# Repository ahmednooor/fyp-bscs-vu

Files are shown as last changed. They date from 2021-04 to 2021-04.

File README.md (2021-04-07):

# IoT based Smart Weather Reporting System

Final year project (CS619 Spring & Fall 2020) for BSCS at Virtual University of Pakistan.

Student Name: Ahmed Noor E Alam

Supervisor: Kalim Ullah

## Introduction

An IoT based system that helps you to monitor live weather data (temperature, humidity and rain) at a location of your choice and set critical limits to get notified when they are crossed.

## Technologies Used

### Hardware Components
1. NodeMCU ESP8266 (Wi-Fi Enabled & Arduino SDK Compatible Microcontroller)
2. DHT22 Temperature + Humidity Sensor
3. YL-83 / MH-RD Rain Drop Sensor
4. U-Blox Neo 6m GPS Module
5. 16x2 I2C LCD Module

### Software Components
1. IoT Device: C/C++ Arduino SDK
2. Web Server: Python Flask
3. Admin Panel: ReactJS
4. Android App: Java Android SDK

## Architectural Overview

<kbd>
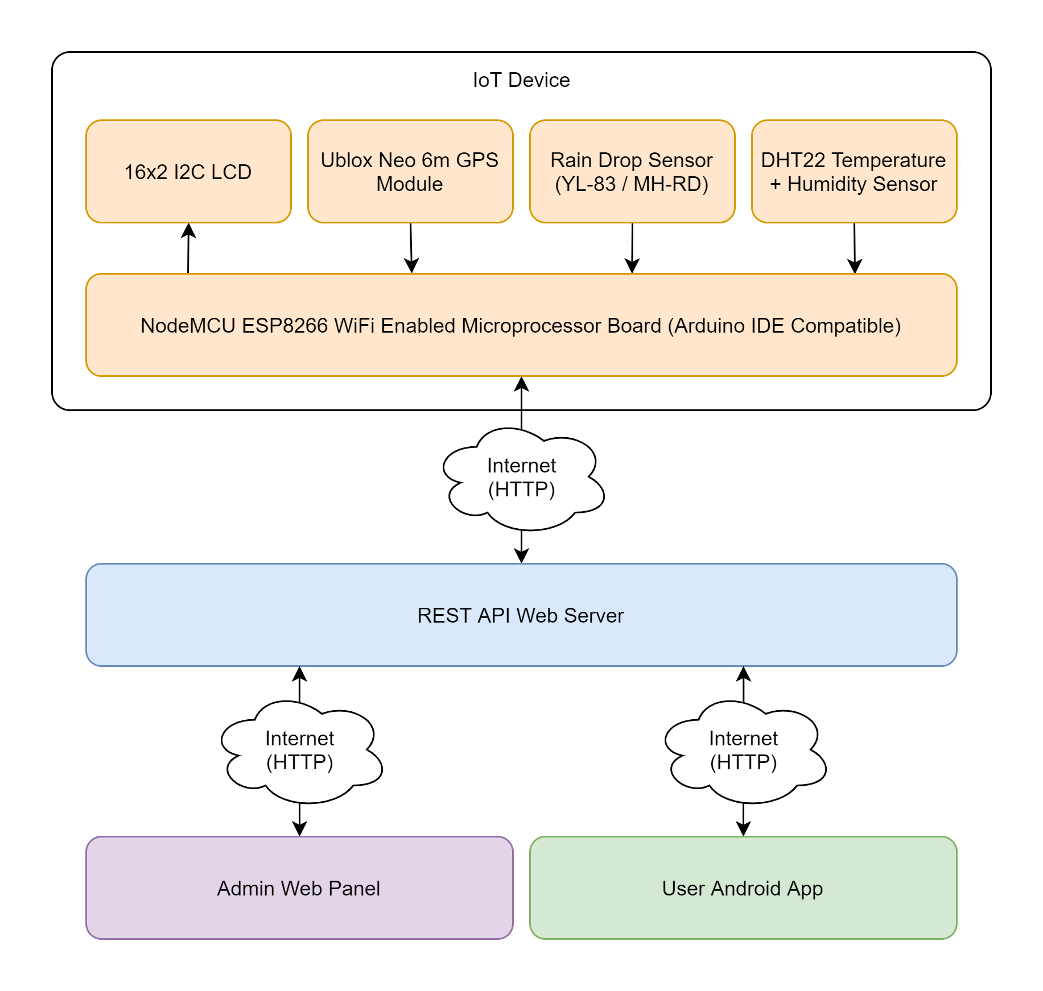
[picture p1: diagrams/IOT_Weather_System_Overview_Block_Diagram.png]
Overview block diagram
    
</kbd>
<br />

## IoT Device Schematic
<kbd>
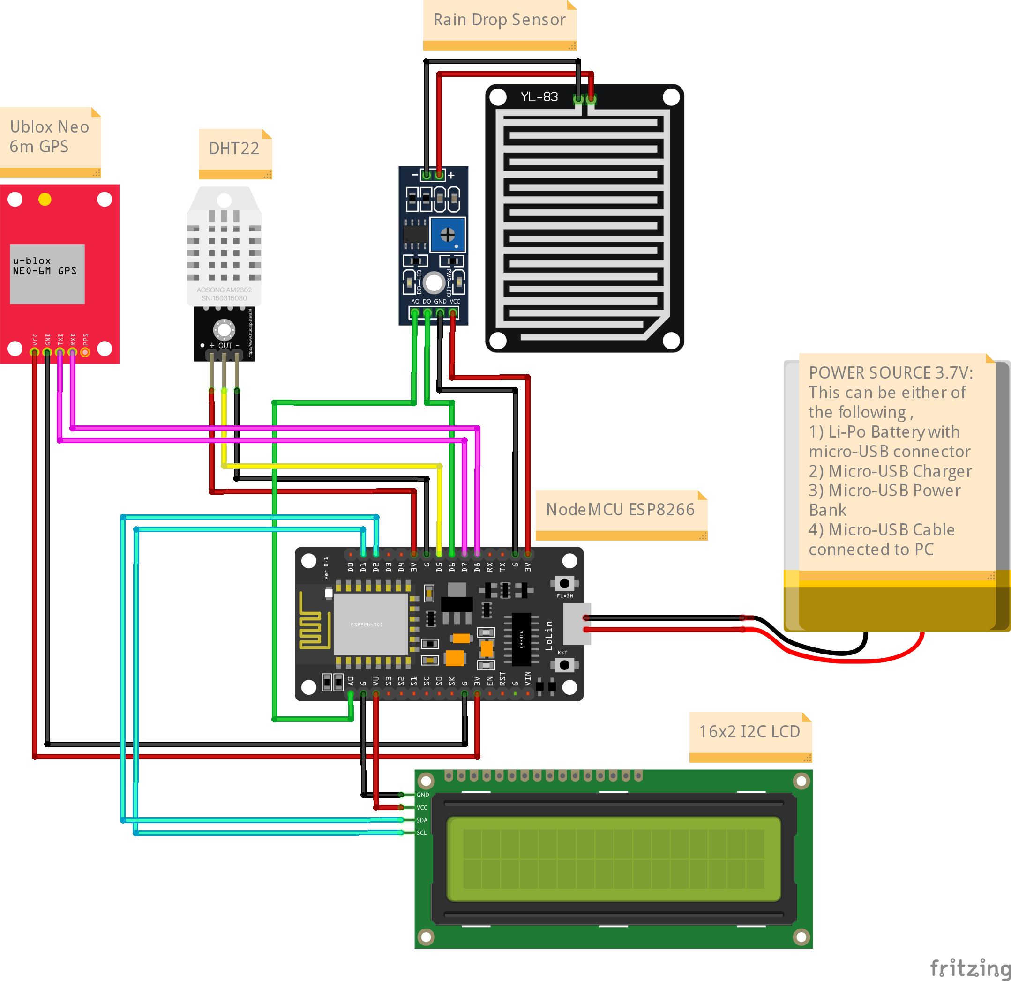
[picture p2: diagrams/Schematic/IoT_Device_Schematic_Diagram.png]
IoT device schematic diagram
    
</kbd>
<br />

### Pin Mappings

| Ublox Neo 6m GPS | NodeMCU ESP8266 |
| --- | --- |
| VCC | 3V3 |
| GND | GND |
| TXD | D7 |
| RXD | D8 |

| DHT 22 | NodeMCU ESP8266 |
| --- | --- |
| + | 3V3 |
| OUT | D5 |
| - | GND |

| Rain Drop Sensor | NodeMCU ESP8266 |
| --- | --- |
| VCC | 3V3 |
| GND | GND |
| DO | D6 |
| AO | A0 |

| 16x2 I2C LCD | NodeMCU ESP8266 |
| --- | --- |
| VCC | VV |
| GND | GND |
| SCL | D1 |
| SDA | D2 |

## PCB Design
<kbd>
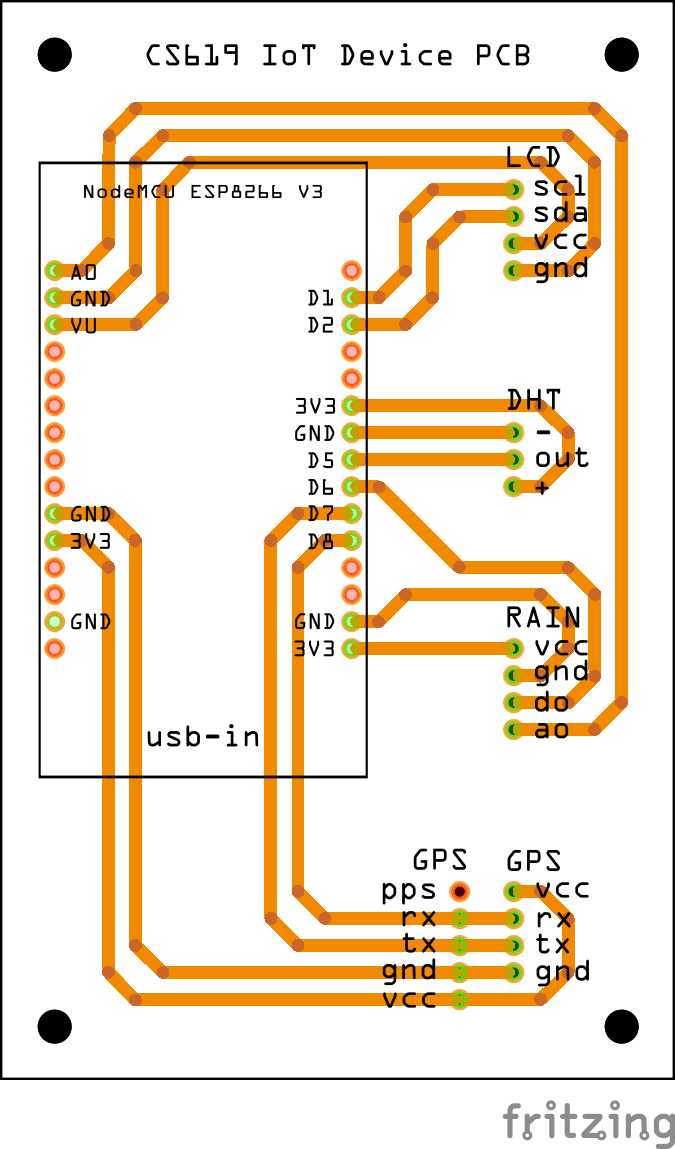
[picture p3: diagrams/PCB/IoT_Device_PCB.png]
PCB design
    
</kbd>
<br />

## Final Deliverable Screenshots and Images

### User Android App
<kbd>
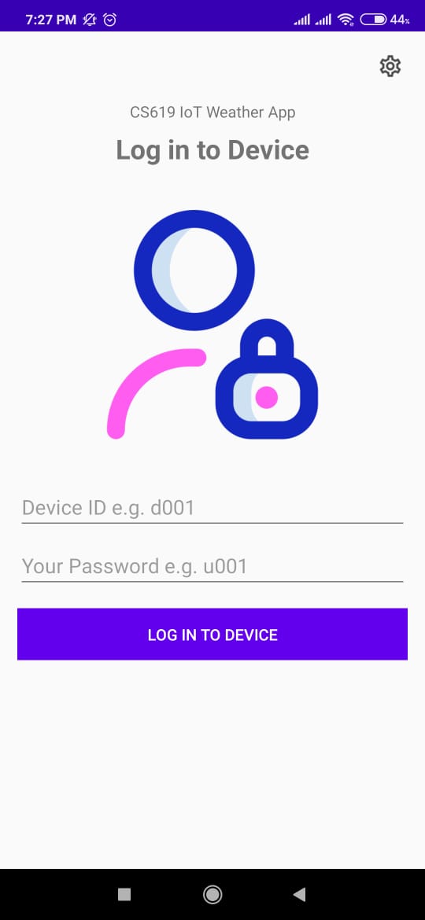
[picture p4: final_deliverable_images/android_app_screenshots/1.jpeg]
User Android app login screenshot
    
</kbd>
<kbd>
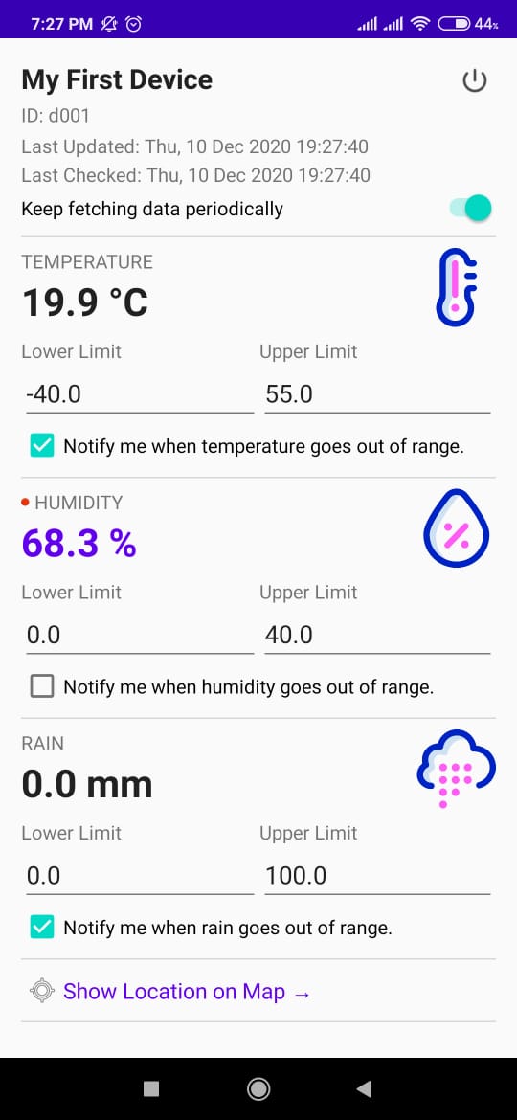
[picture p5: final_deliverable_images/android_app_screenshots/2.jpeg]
User Android app dashboard screenshot
    
</kbd>
<kbd>
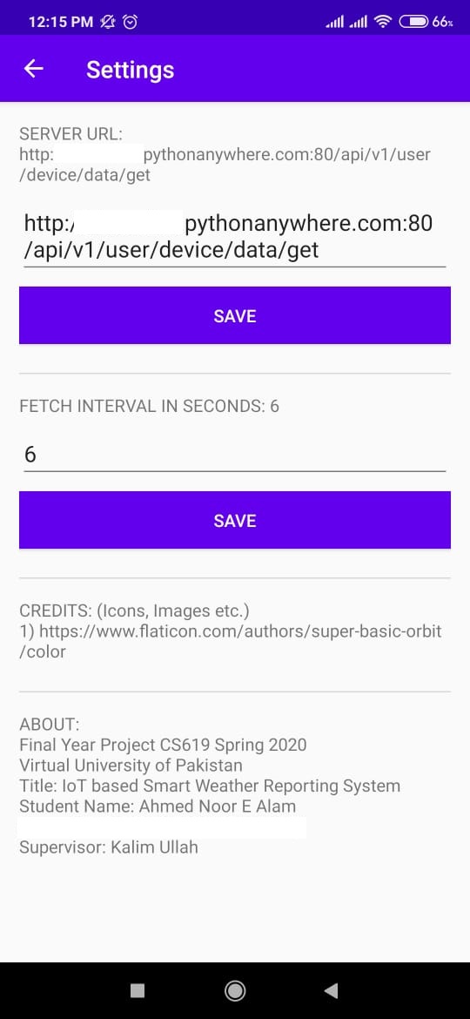
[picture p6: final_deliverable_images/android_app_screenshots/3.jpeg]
User Android app settings screenshot
    
</kbd>
<br />

### IoT Device
<kbd>
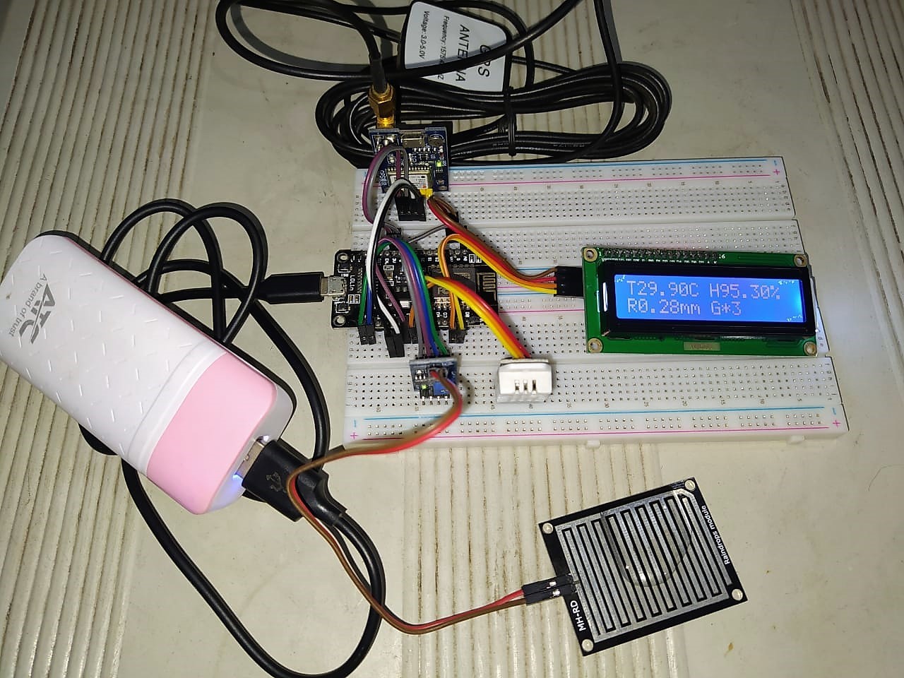
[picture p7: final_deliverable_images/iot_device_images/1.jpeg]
IoT device image
    
</kbd>
<kbd>
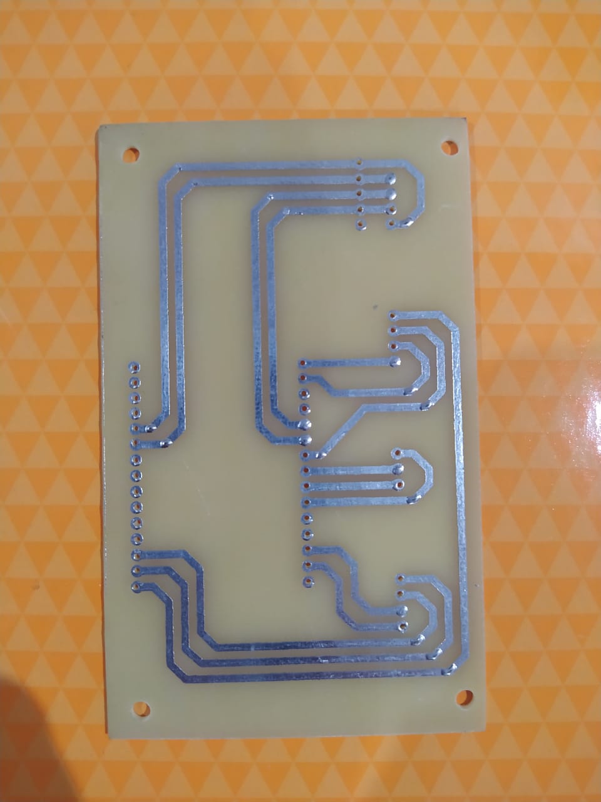
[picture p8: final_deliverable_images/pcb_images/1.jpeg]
PCB image
    
</kbd>
<br />
<kbd>
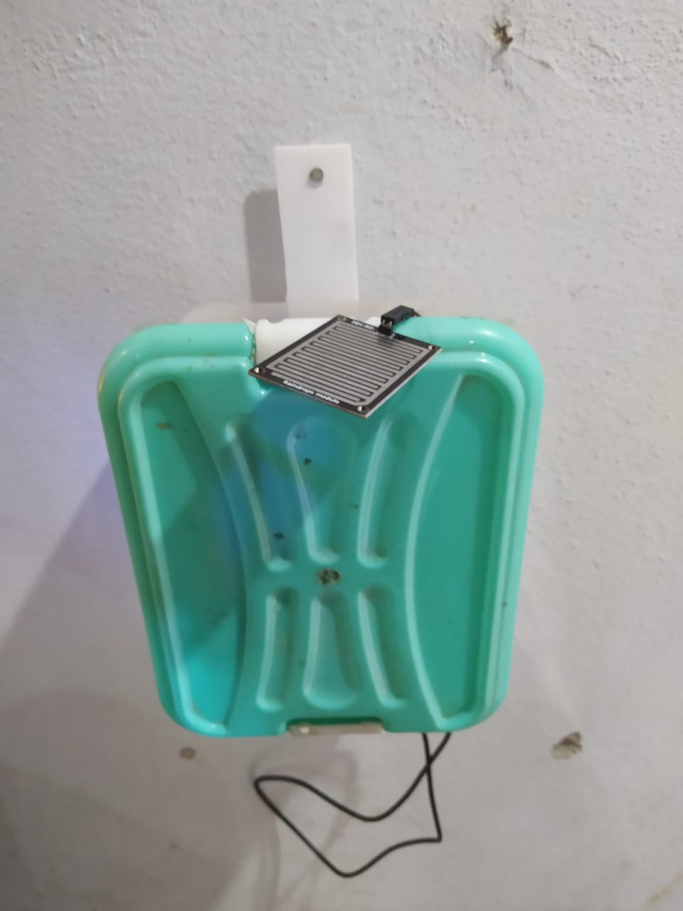
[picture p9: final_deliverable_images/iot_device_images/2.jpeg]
IoT device image
    
</kbd>
<kbd>
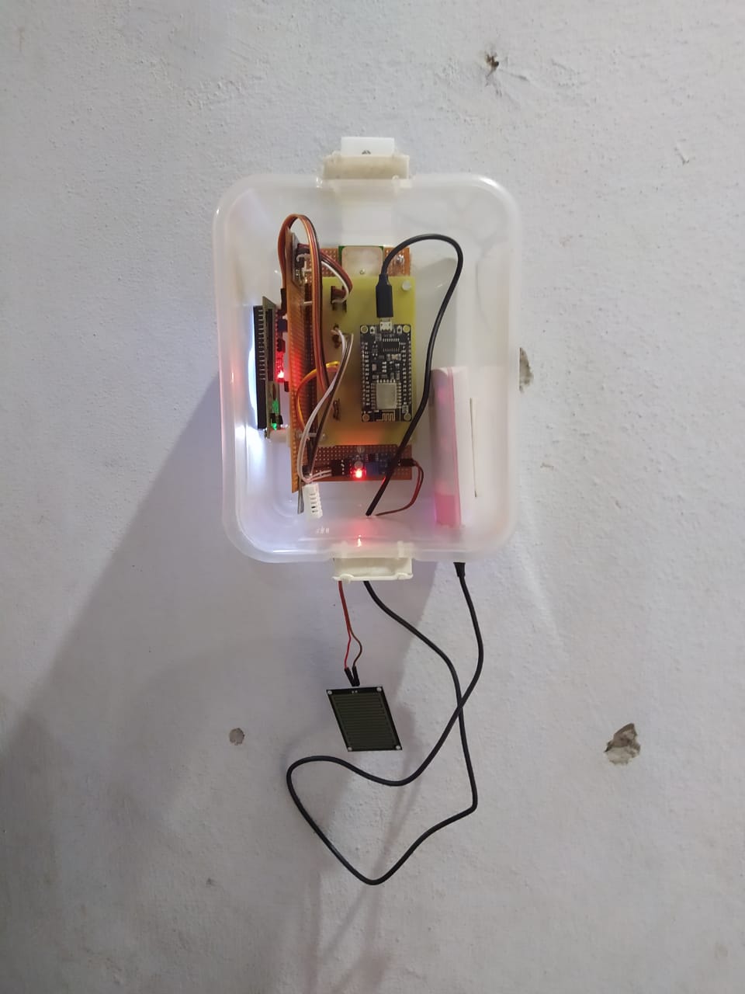
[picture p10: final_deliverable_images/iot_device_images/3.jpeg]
IoT device image
    
</kbd>
<br />
<kbd>
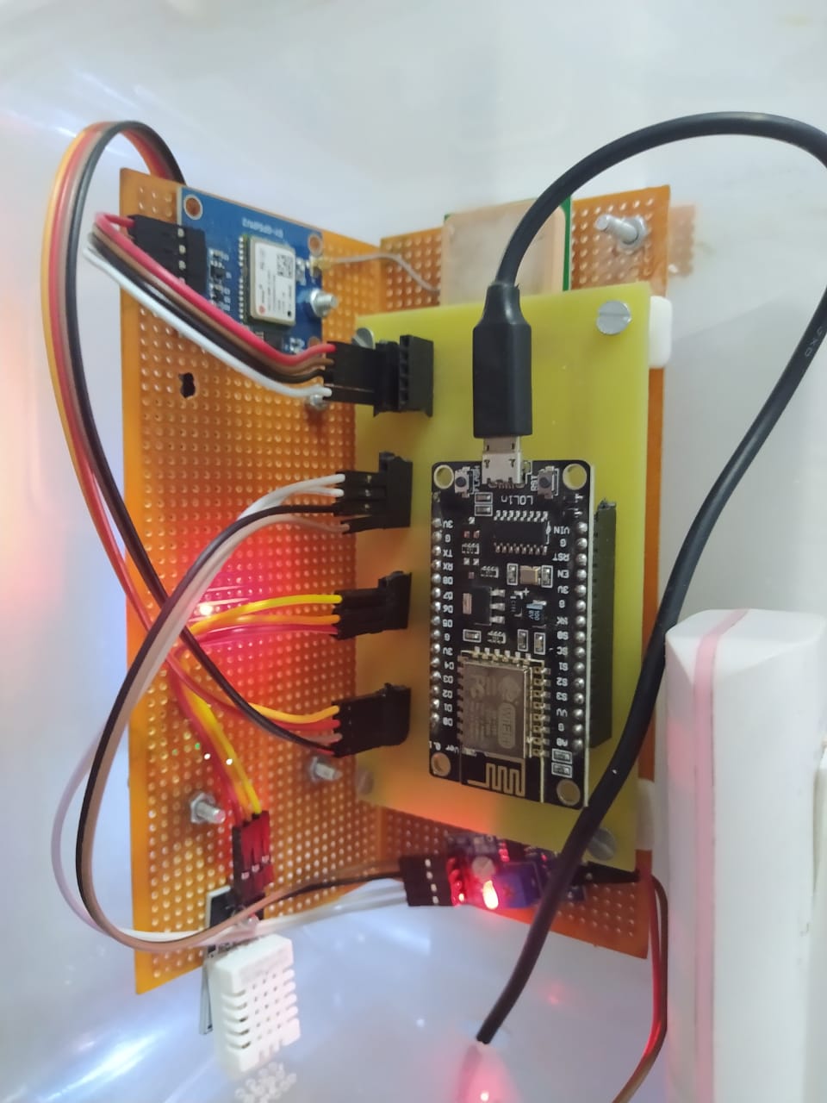
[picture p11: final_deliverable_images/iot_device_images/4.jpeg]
IoT device image
    
</kbd>
<kbd>
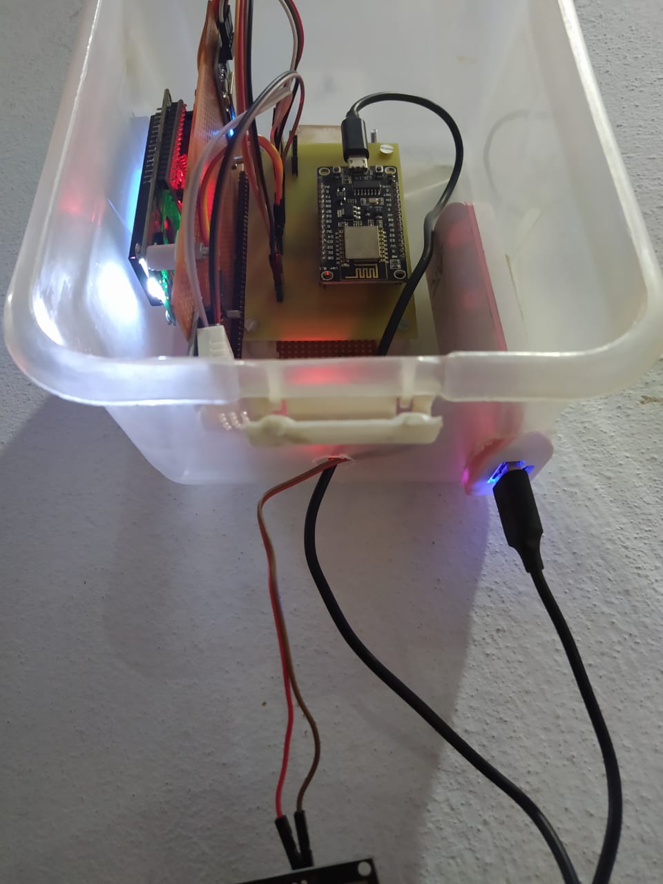
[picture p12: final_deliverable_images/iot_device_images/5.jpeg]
IoT device image
    
</kbd>
<br />
<kbd>
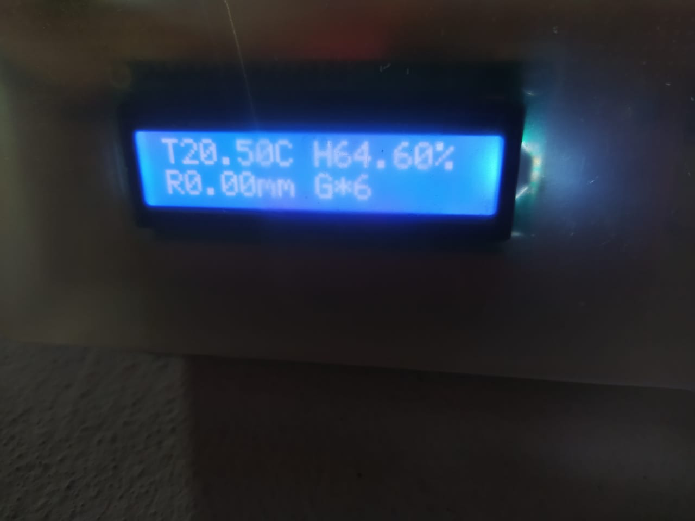
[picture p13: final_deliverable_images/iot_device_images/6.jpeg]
IoT device image
    
</kbd>
<br />

### Admin Web Panel
<kbd>
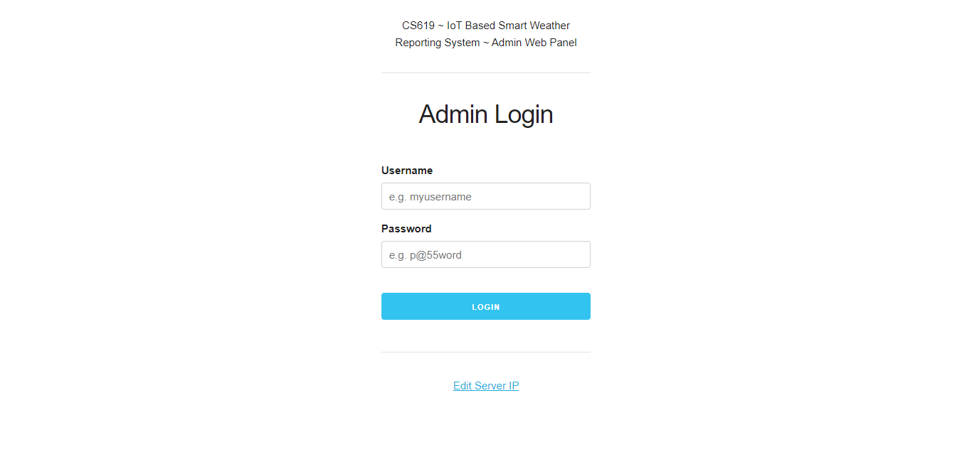
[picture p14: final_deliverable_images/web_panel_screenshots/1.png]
Admin web panel login screenshot
    
</kbd>
<br>
<kbd>
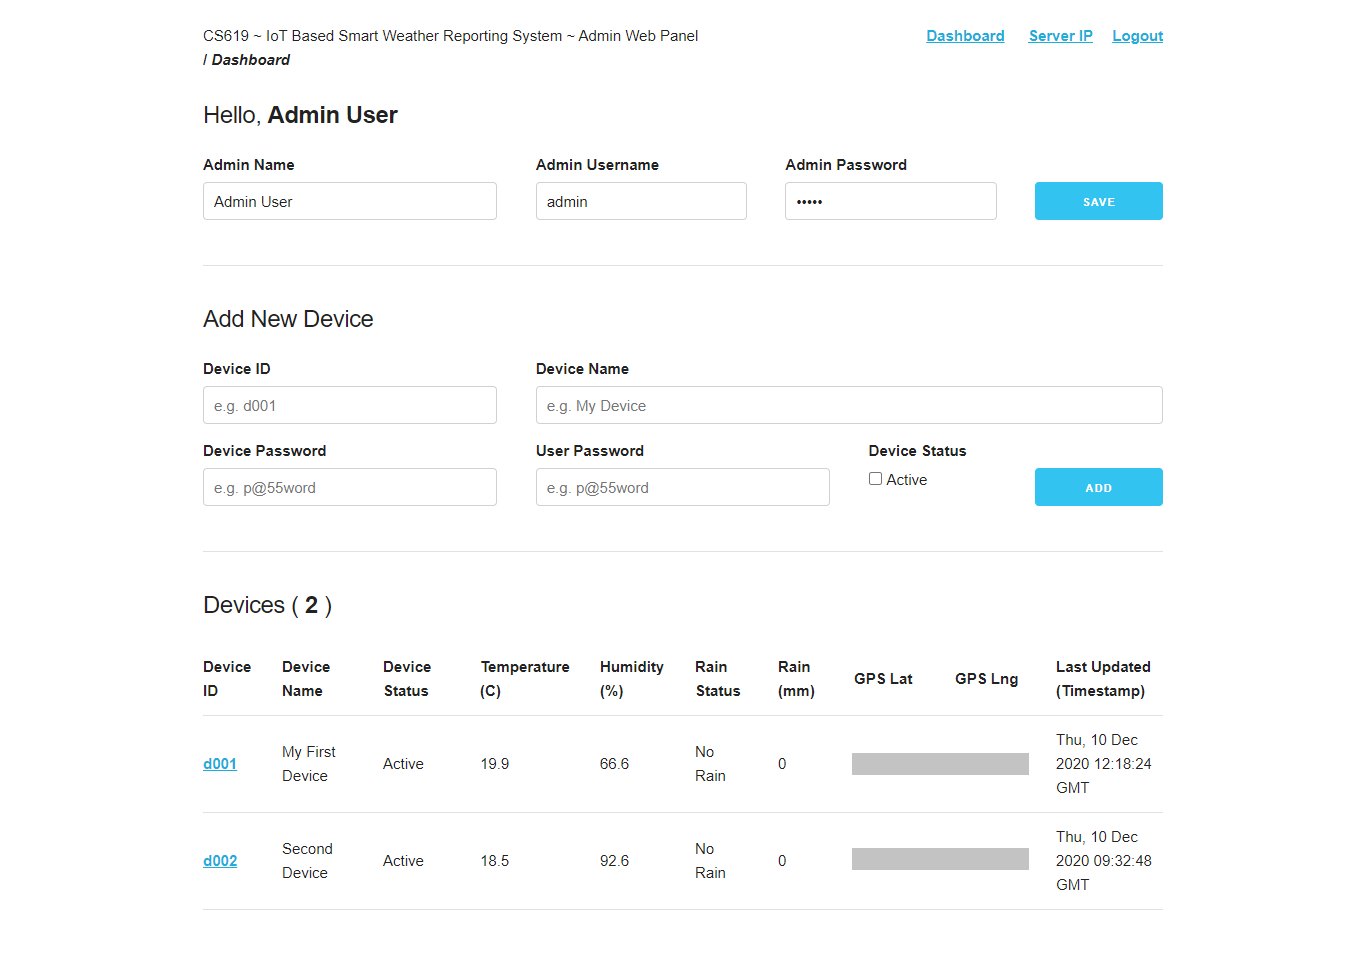
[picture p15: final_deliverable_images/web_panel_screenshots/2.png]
Admin web panel dashboard screenshot
    
</kbd>
<br>
<kbd>
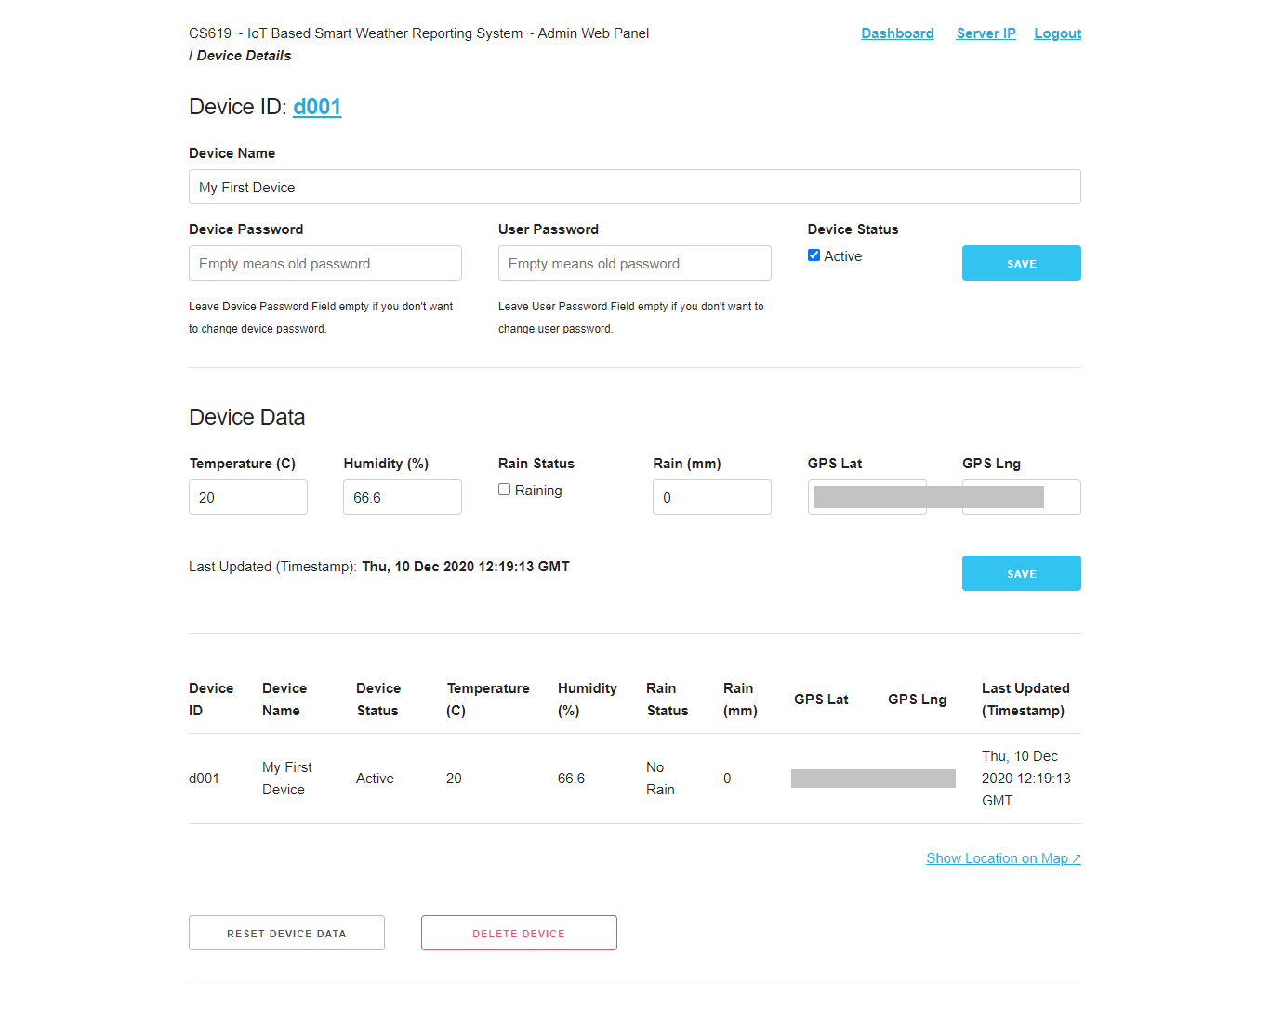
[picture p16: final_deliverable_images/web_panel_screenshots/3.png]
Admin web panel device page screenshot
    
</kbd>
<br>
<kbd>
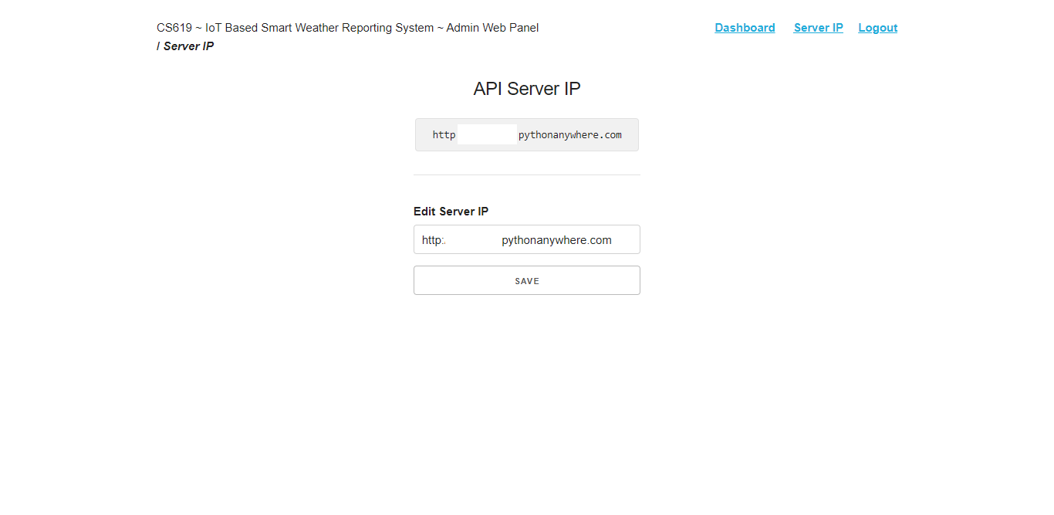
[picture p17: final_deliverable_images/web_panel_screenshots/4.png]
Admin web panel server ip page screenshot
    
</kbd>
<br>

## Setup and Usage Instructions

The system has four components.

1. Python Web Server
2. Admin Web Panel
3. IoT Device
4. User Android App

### 1. Python Server (Deploy on pythonanywhere.com):

1. Copy contents of `rest_api_web_server` in to a directory with the same name on pythonanywhere via either uploading a zip and then unzipping via opening a terminal or via cloning the git repo.
2. Creat new flask web app in root of the same directory. Just make sure the new file name should not override any pre-existing ones. By default the new file is named `flask_app.py`.
3. Clear the contents of the newly created `flask_app.py` file and add `from run import app` then save and reload the web app.

**The following details will be used for setting up the remaining components.**
- **Server IP:** &lt;your_username&gt;.pythonanywhere.com
  > Or if you deployed on a VPS, then your vps host name or ip.
- **Port:** 80 
  > Or if you deployed your app on other port, use that.
- **DEFAULT_SERVER_URL** i.e. ip+port+api_endpoint for android app: http://&lt;your_username&gt;.pythonanywhere.com:80/api/v1/user/device/data/get

### 2. Admin Web Panel:

1. Open terminal in `admin_web_panel` directory.
2. Type `npm install`.
3. Type `npm run build`. You will get the build of your web app in `build` directory.
4. Open `index.html` in browser and go to `Server IP` link and edit the server ip with yours. You don't need to add api_endpoint in the field. Just server ip + port e.g. `http://<your_username>.pythonanywhere.com:80`
5. Login with admin credentials. Default username is `admin` and password is `12345`.
6. Add a new device with new `Device ID`, `Device Password` and `User Password`.
   > Make sure that you check the `active` box while creating a new device, otherwise the server will not store new data from that device.

### 3. IoT Device:

1. Install ESP8266 Core Library for Arduino IDE by following the tutorial from the link below.
   > Link: https://randomnerdtutorials.com/how-to-install-esp8266-board-arduino-ide/
2. Unzip and copy the contents of `iot_device/libraries.zip` in to the libraries folder of your Arduino user directory i.e. `"This PC/Documents/Arduino/libraries/"`.
3. Check the `Schematic Diagram` from `diagrams` directory for wiring details and attach all the components to the board according to the wiring shown in the diagram.
4. Open `iot_device/ESP8266_Sketch/ESP8266_Sketch.ino` in your Arduino IDE and update your WiFi Name `#define SSID "..."` and WiFi Password `#define PASS "..."`.
5. Update `#define REST_SERVER_IP "..."` with your Server IP e.g. `http://<your_username>.pythonanywhere.com` and `#define REST_SERVER_PORT "..."` with the port where you deployed the python server  e.g. `:80`.
6. Copy the same `Device ID` and `Device Password` that you entered in the `Admin Web Panel`, and paste them in your IoT Sketch for `#define DEVICE_ID "..."` and `#define DEVICE_PASSWORD "..."`.
5. Connect your board to computer with Micro USB cable, and then select `NodeMCU v1.0 (ESP-12E Module)` from `Tools > Board: > ...` just like in installation instruction, then select `com port` and upload the sketch. Open Serial Monitor in your Arduino IDE to see output.
   > Note: The GPS module takes some time to connect to satellites.

### 4. User Android App:

1. Open in android studio.
2. Open `DatabaseActivity` and edit `DEFAULT_SERVER_URL` with your server url i.e. host + port + api_endpoint.
   e.g. `DEFAULT_SERVER_URL = "http://<your_username>.pythonanywhere.com:80/api/v1/user/device/data/get"`
3. Add `google_maps_key` in `.../src/debug/res/values/google_maps_api.xml` and `.../src/release/res/values/google_maps_api.xml` with your api key.
4. Run the app or build apk and install.
5. Use the same `Device ID` and `User Password` that you entered in the `Admin Web Panel`, and enter it in the login screen of mobile app to login and access device data.

~ *End of file.* ~

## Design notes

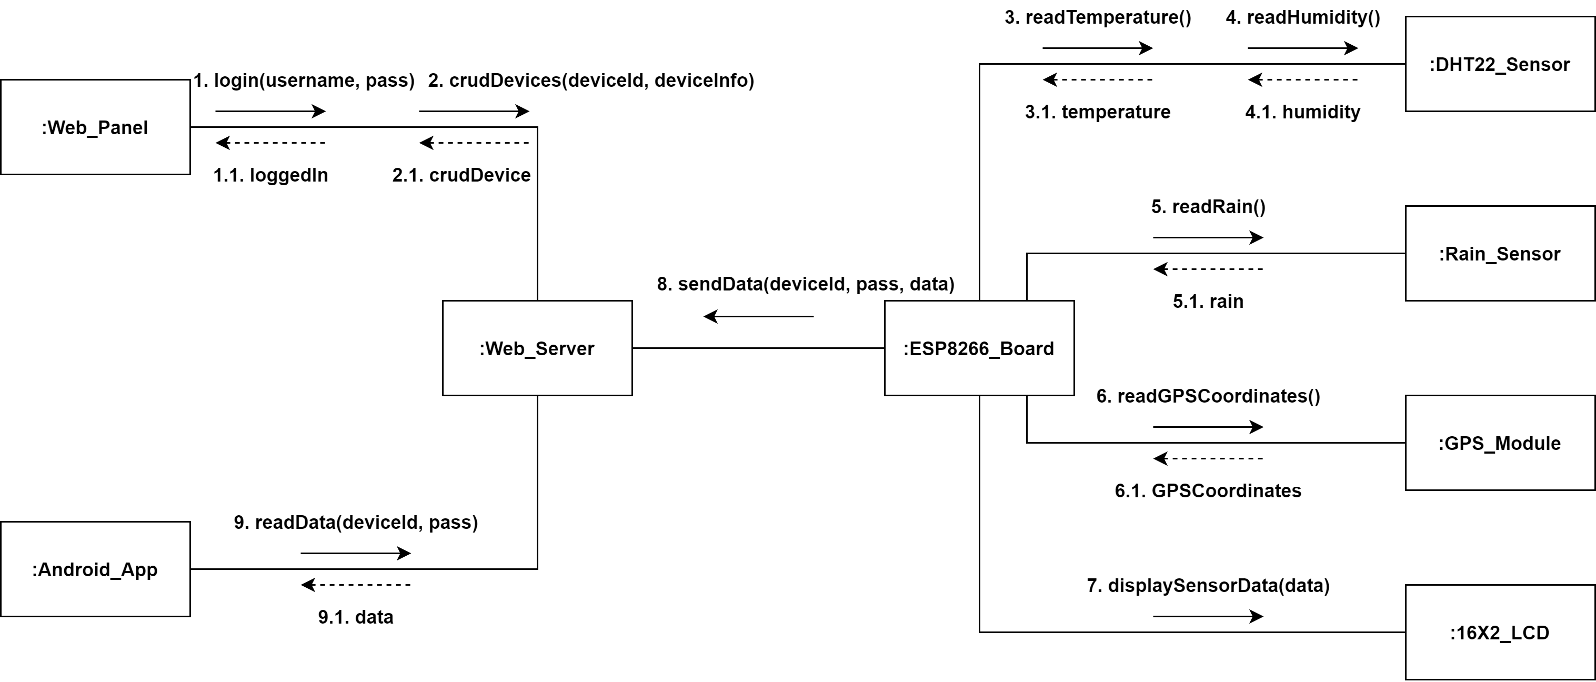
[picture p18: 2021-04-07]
diagrams/Communication_Diagram.png

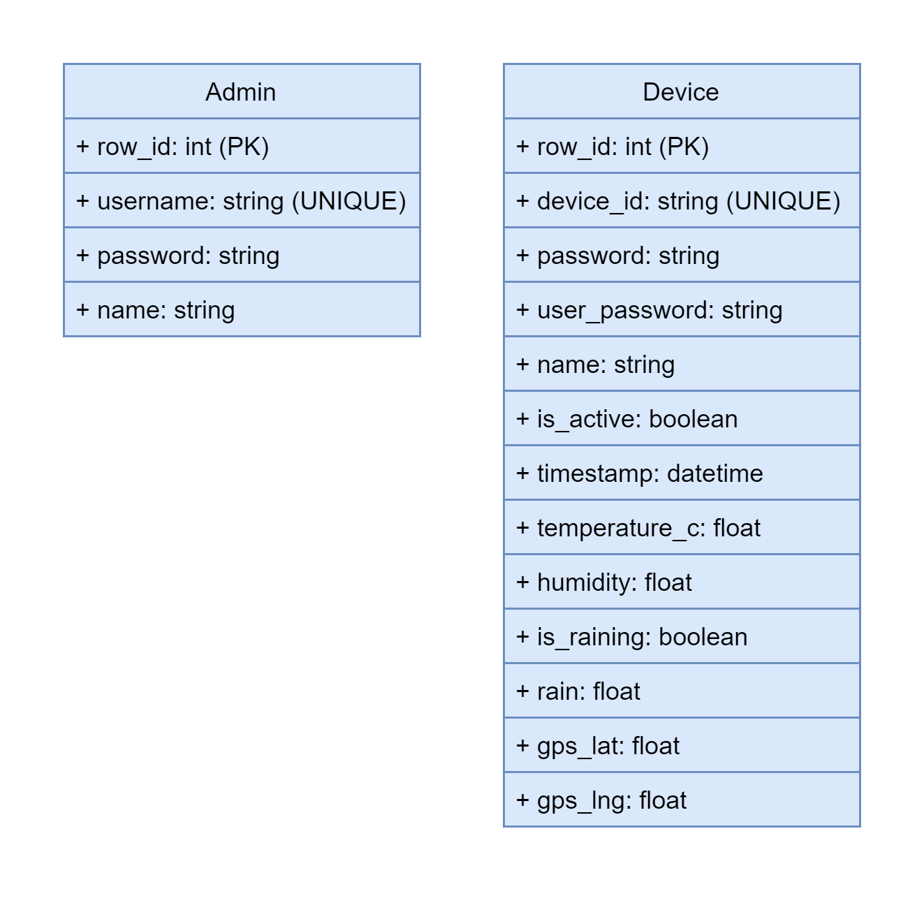
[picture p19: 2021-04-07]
diagrams/Database_Tables.png

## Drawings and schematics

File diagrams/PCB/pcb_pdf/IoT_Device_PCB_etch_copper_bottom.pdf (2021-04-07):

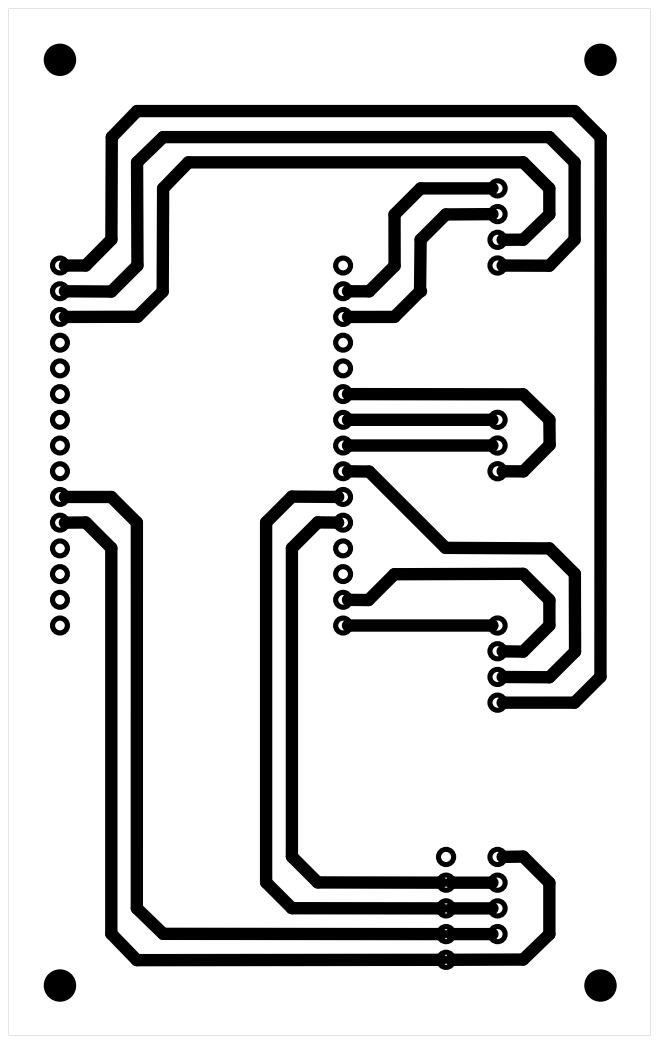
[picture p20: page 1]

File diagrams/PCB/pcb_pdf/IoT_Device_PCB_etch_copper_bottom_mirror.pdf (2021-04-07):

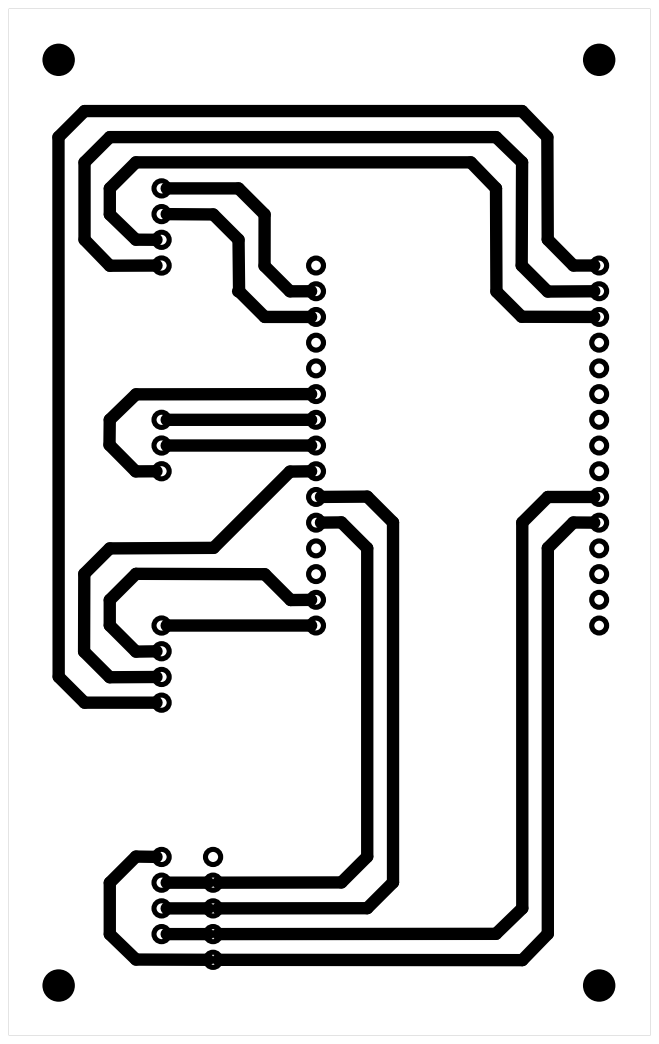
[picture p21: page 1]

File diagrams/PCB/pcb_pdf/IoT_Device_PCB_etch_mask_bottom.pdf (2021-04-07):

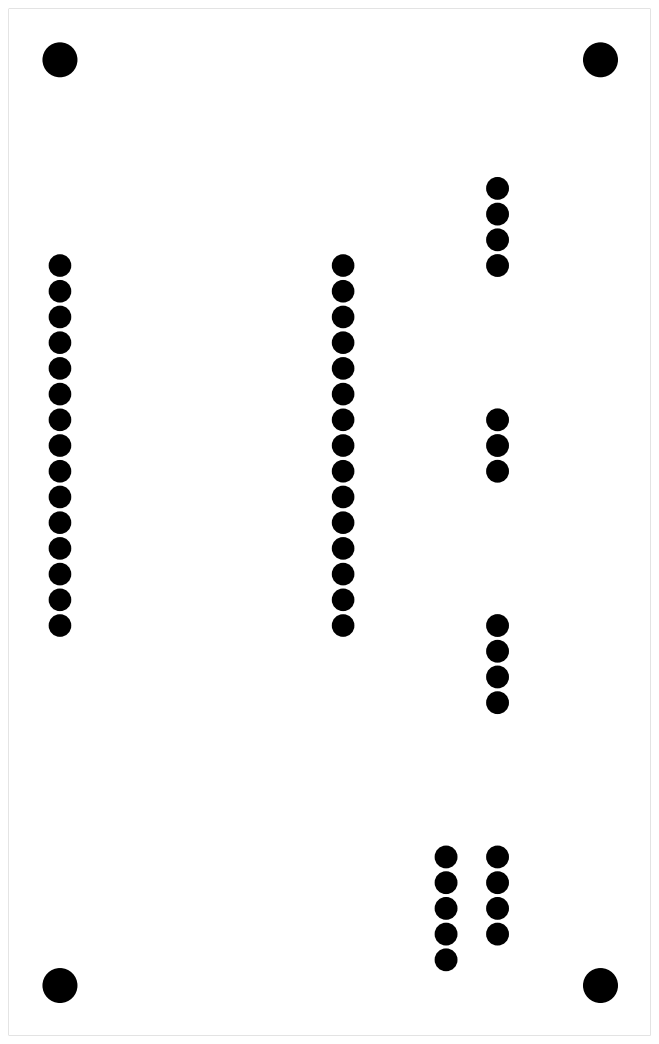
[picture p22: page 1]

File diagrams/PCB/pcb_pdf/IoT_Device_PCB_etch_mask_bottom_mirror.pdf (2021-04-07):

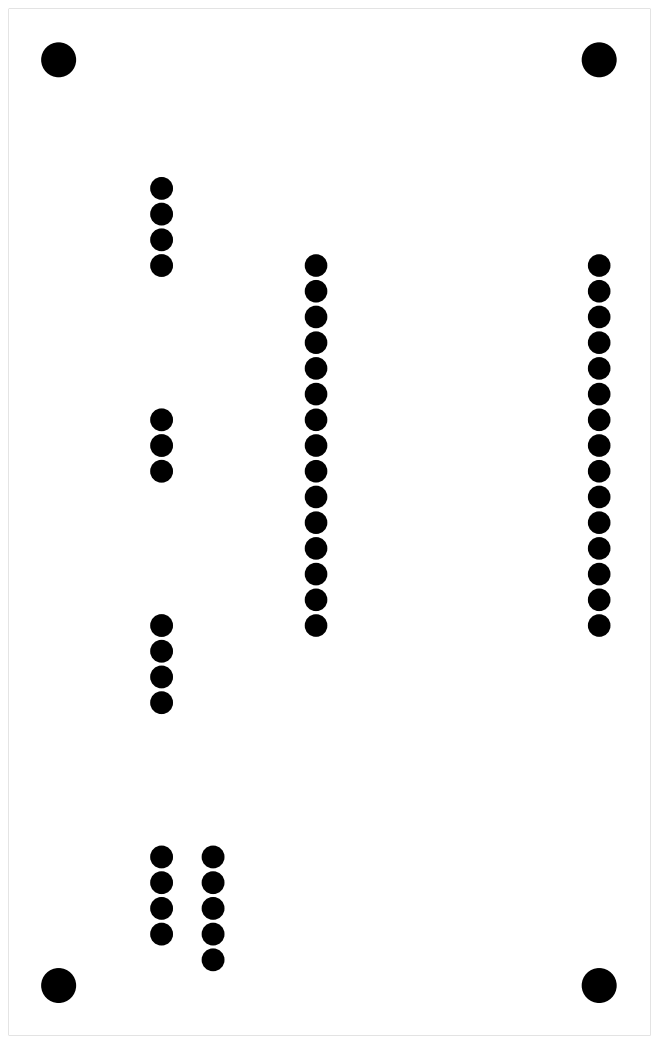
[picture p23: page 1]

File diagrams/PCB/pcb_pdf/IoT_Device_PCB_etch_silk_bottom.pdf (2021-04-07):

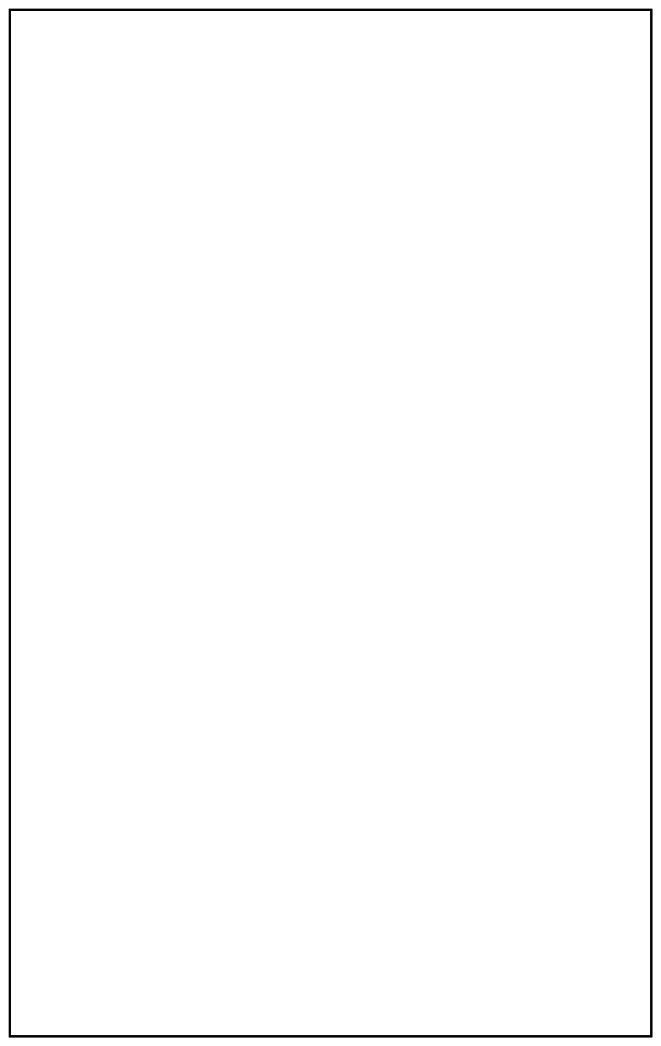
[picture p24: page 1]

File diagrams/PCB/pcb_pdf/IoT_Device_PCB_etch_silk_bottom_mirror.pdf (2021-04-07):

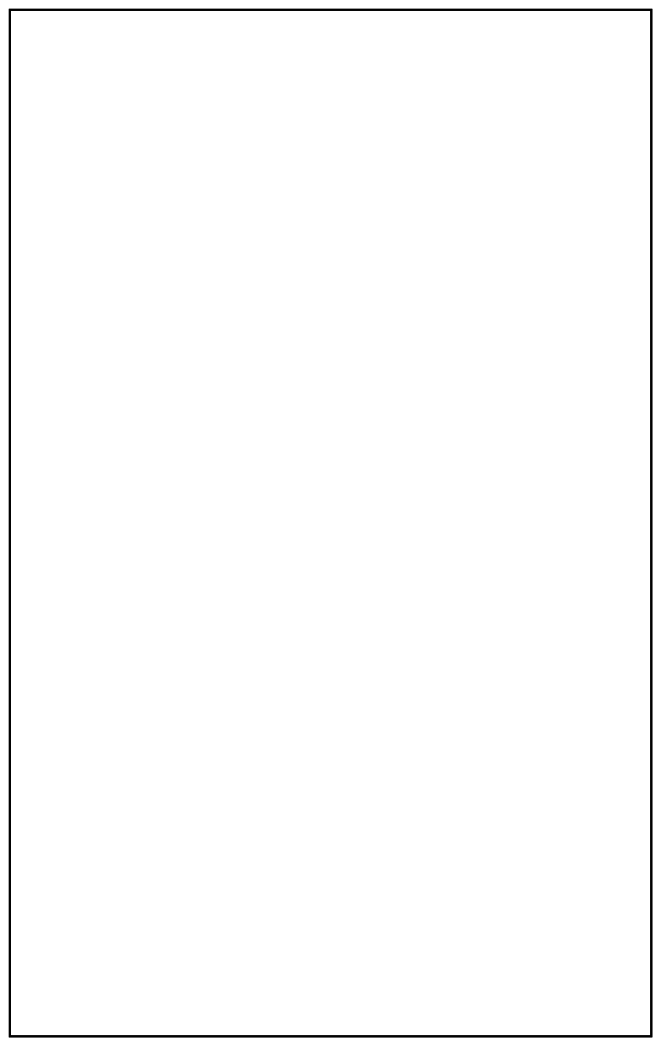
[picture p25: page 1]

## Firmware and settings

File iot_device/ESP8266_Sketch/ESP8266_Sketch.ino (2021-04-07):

// CS619 VU FYP Spring 2020
// Useful links and credits:
// https://robojax.com/learn/arduino/?vid=robojax_ESP8266_NodeMCU_DHT
// https://github.com/sarful/Interface-raindrop-sensor-to-NodeMcu-For-Beginner/blob/master/rain_sensor.ino.ino
// https://cdn.instructables.com/FJC/J4AP/JH8JBTHA/FJCJ4APJH8JBTHA.LARGE.jpg
// https://lastminuteengineers.com/wp-content/uploads/arduino/ESP-12E-Development-Board-ESP8266-NodeMCU-Pinout.png

#include <math.h>
#include <DHT.h>
#include <Adafruit_Sensor.h>

#include <ESP8266WiFi.h>
#include <WiFiClient.h>
#include <ESP8266WebServer.h>
#include <ESP8266mDNS.h>
#include <ESP8266HTTPClient.h>

#include <TinyGPS++.h>
#include <SoftwareSerial.h>

#include <Wire.h>
#include <LiquidCrystal_I2C.h>

// --- Digital (Dx) GPIO Pin Mappings ---
#define PIN_D0 16
#define PIN_D1 5
#define PIN_D2 4
#define PIN_D3 0
#define PIN_D4 2
#define PIN_D5 14
#define PIN_D6 12
#define PIN_D7 13
#define PIN_D8 15

// --- DHT settings ---
#define DHTPIN PIN_D5 // what digital pin we're connected to
// Uncomment "DHTTYPE" the one you're using!
// #define DHTTYPE DHT11   // DHT 11
#define DHTTYPE DHT22 // DHT 22  (AM2302), AM2321
// #define DHTTYPE DHT21   // DHT 21 (AM2301)
DHT dht(DHTPIN, DHTTYPE);
float temperatureC = 0.0; // temperature in Celsius
float humidity = 0.0;     // humidity in %

// --- Rain Drop Sensor Settings ---
#define RAIN_ANALOGUE_PIN A0    // input for LDR and rain sensor
#define RAIN_DIGITAL_PIN PIN_D6 // enable reading Rain sensor
int rainAnalogueValue = 0;      // variable to store the value coming from Rain sensor
int rainDigitalValue = 0;       // variable to store the value coming from Rain sensor
double rainMeasure = 0.0;       // variable to store rain measurement in mm

// --- gps settings ---
TinyGPSPlus gps;
#define RXPin PIN_D7             // TX from gps goes into RX of board
#define TXPin PIN_D8             // RX from gps goes into TX of board
SoftwareSerial gpsSerial(RXPin, TXPin); // (RX, TX) The serial connection to the GPS device
float latitude, longitude;
int year, month, date, hour, minute, second;
String date_str, time_str, lat_str, lng_str;
int pm;
uint32_t sats = 0;
// NOTE: also see https://www.esp8266.com/viewtopic.php?f=32&t=3829

// --- lcd settings ---
// set LCD address, number of columns and rows
// if you don't know your display address, run an I2C scanner sketch
#define LCD_ADDR 0x27 // I2C LCD Address: 0x27
#define LCD_COL 16
#define LCD_ROW 2
LiquidCrystal_I2C lcd(LCD_ADDR, LCD_COL, LCD_ROW);
bool shouldShowGpsCoordinates = false;

// --- wifi settings ---
#define SSID "..."    // Your WiFi name
#define PASS "..."    // Your WiFi password
ESP8266WebServer server(80); // on-board web server on port 80

// --- rest api http web server settings ---
#define REST_SERVER_IP "http://<your_username>.pythonanywhere.com"       // ip/domain of server
#define REST_SERVER_PORT ":80"                      // port at which api is running
#define REST_SERVER_ROUTE "/api/v1/device/data/update"     // route that handles put request from device

// --- device settings ---
#define DEVICE_ID "d001"            // device id added by admin
#define DEVICE_PASSWORD "p001"      // device password added by admin

void setup(void)
{
    // set baud rate for seriial monitor
    Serial.begin(115200);

    // setup dht
    dht.begin();

    // setup rain sensor pins
    pinMode(RAIN_DIGITAL_PIN, INPUT);
    pinMode(RAIN_ANALOGUE_PIN, INPUT);

    // set baud rate for serial conn to gps
    gpsSerial.begin(9600);

    // initialize LCD
    // lcd.begin();
    lcd.begin(PIN_D2, PIN_D1);
    lcd.backlight(); // turn on LCD backlight

    connectToWiFi();

    // setup web server routes
    server.on("/", indexRouteHandler);
    // server.on("/inline", // demo for other routes
    //           []() {
    //               server.send(200, "text/plain", "this works as well");
    //           });
    server.onNotFound(routeNotFound);

    server.begin();
    Serial.println("HTTP server started");
}

void loop(void)
{
    server.handleClient();
    MDNS.update();


    // read temperature and humidity
    float newTemperatureC = dht.readTemperature();     // Read temperature as Celsius (the default)
    float newHumidity = dht.readHumidity();            // Reading humidity

    temperatureC = !isnan(newTemperatureC) ? newTemperatureC : -1000.0;
    humidity = !isnan(newHumidity) ? newHumidity : -1000.0;


    // read rain sensor
    rainAnalogueValue = analogRead(RAIN_ANALOGUE_PIN);
    rainDigitalValue = digitalRead(RAIN_DIGITAL_PIN);

    // the rain measure is based on the ratio of change in analogue value when water is present and 
    // total analogue value when no water is pressent. 0.5mm is the height of water if the whole sensor
    // is covered with water. This measure is instantaneous rather than time oriented.
    rainMeasure = rainDigitalValue == 0
                      ? ((double)(1024 - rainAnalogueValue) / 1024.00) * 0.5
                      : 0.00;


    // read GPS coordinates
    readDataFromGPS();


    // print data on serial monitor
    Serial.println("");
    Serial.println("--- Sensors Data ---");

    Serial.print("TMP: ");
    Serial.print(temperatureC != -1000.0 ? String(temperatureC, 2) : "--");
    Serial.println(" °C");
    
    Serial.print("HMD: ");
    Serial.print(humidity != -1000.0 ? String(humidity, 2) : "--");
    Serial.println(" %");
    
    Serial.print("RAN: ");
    Serial.print(rainMeasure);
    Serial.println(" mm");

    Serial.println("--- GPS Data ---");
    
    Serial.print("SAT: ");
    Serial.println(sats);
    Serial.print("LAT: ");
    Serial.println(lat_str != "" ? lat_str : "--");
    Serial.print("LNG: ");
    Serial.println(lng_str != "" ? lng_str : "--");
    Serial.println("");


    // print data on 16*2 LCD
    if (shouldShowGpsCoordinates)
    {
        lcd.clear();
        lcd.setCursor(0, 0);
        lcd.print("LAT ");
        lcd.print(lat_str != "" ? lat_str : "--");
        lcd.setCursor(0, 1);
        lcd.print("LNG ");
        lcd.print(lng_str != "" ? lng_str : "--");
        shouldShowGpsCoordinates = false;
    }
    else
    {
        lcd.clear();
        lcd.setCursor(0, 0);
        lcd.print("T");
        lcd.print(temperatureC != -1000.0 ? String(temperatureC, 2) : "--");
        lcd.print("C ");
        lcd.print("H");
        lcd.print(humidity != -1000.0 ? String(humidity, 2) : "--");
        lcd.print("% ");
        lcd.setCursor(0, 1);
        lcd.print("R");
        lcd.print(rainMeasure);
        lcd.print("mm ");
        lcd.print("G*");
        lcd.print(sats);
        shouldShowGpsCoordinates = true;
    }

    // send data to server
    sendJSONPayloadToServer(REST_SERVER_IP, REST_SERVER_PORT, REST_SERVER_ROUTE);

    lat_str = "";
    lng_str = "";
    
    // standard advised delay is 2000 for dht22
    // smartDelay helps to read data from gps while delaying
    smartDelay(2000);
}

void sendJSONPayloadToServer(String ip, String port, String route)
{
    // wait for WiFi connection
    if ((WiFi.status() == WL_CONNECTED))
    {

        WiFiClient client;
        HTTPClient http;

        Serial.print("[HTTP] begin...\n");
        // configure target server and url
        String url = ip + port + route;
        http.begin(client, url);
        http.addHeader("Content-Type", "application/json");

        Serial.print("[HTTP] POST...\n");
        // start connection and send HTTP header and body
        int httpCode = http.POST(generateJSONPayload());

        // httpCode will be negative on error
        if (httpCode > 0)
        {
            // HTTP header has been sent and Server response header has been handled
            Serial.printf("[HTTP] POST... code: %d\n", httpCode);

            const String &payload = http.getString();
            Serial.println("received payload:\n<<");
            Serial.println(payload);
            Serial.println(">>");
        }
        else
        {
            Serial.printf("[HTTP] POST... failed, error: %s\n", http.errorToString(httpCode).c_str());
        }

        http.end();
    }
    else
    {
        connectToWiFi();
    }
}

void readDataFromGPS()
{
    sats = gps.satellites.value(); // read num of conneceted satellites

    while (gpsSerial.available() > 0) //while data is available
    {
        char c = gpsSerial.read();
        // Serial.print(c);
        
        gps.encode(c);
        if (gps.location.isValid()) //check whether gps location is valid
        {
            latitude = gps.location.lat();
            lat_str = String(latitude, 6); // latitude location is stored in a string
            longitude = gps.location.lng();
            lng_str = String(longitude, 6); //longitude location is stored in a string
        }

        if (gps.date.isValid()) //check whether gps date is valid
        {
            date_str = "";
            date = gps.date.day();
            month = gps.date.month();
            year = gps.date.year();
            if (date < 10)
                date_str = '0';
            date_str += String(date); // values of date,month and year are stored in a string
            date_str += " / ";

            if (month < 10)
                date_str += '0';
            date_str += String(month); // values of date,month and year are stored in a string
            date_str += " / ";
            if (year < 10)
                date_str += '0';
            date_str += String(year); // values of date,month and year are stored in a string
        }
        if (gps.time.isValid()) //check whether gps time is valid
        {
            time_str = "";
            hour = gps.time.hour();
            minute = gps.time.minute();
            second = gps.time.second();
            minute = (minute + 30); // converting to IST
            if (minute > 59)
            {
                minute = minute - 60;
                hour = hour + 1;
            }
            hour = (hour + 5);
            if (hour > 23)
                hour = hour - 24; // converting to IST
            if (hour >= 12)       // checking whether AM or PM
                pm = 1;
            else
                pm = 0;
            hour = hour % 12;
            if (hour < 10)
                time_str = '0';
            time_str += String(hour); //values of hour,minute and time are stored in a string
            time_str += " : ";
            if (minute < 10)
                time_str += '0';
            time_str += String(minute); //values of hour,minute and time are stored in a string
            time_str += " : ";
            if (second < 10)
                time_str += '0';
            time_str += String(second); //values of hour,minute and time are stored in a string
            if (pm == 1)
                time_str += " PM ";
            else
                time_str += " AM ";
        }
    }
}

// This custom version of delay() ensures that the gps object is being "fed".
static void smartDelay(unsigned long ms)
{
    unsigned long start = millis();
    do
    {
        readDataFromGPS();
    } while (millis() - start < ms);
}

void connectToWiFi()
{
    // connect to wifi
    WiFi.mode(WIFI_STA);
    WiFi.begin(SSID, PASS);
    Serial.println("");

    lcd.clear();
    lcd.setCursor(0, 0);
    lcd.print("Connecting...");
    delay(1000);

    // Wait for connection
    while (WiFi.status() != WL_CONNECTED)
    {
        delay(500);
        Serial.print(".");
    }
    if (WiFi.status() == WL_CONNECTED)
    {
        lcd.clear();
        lcd.setCursor(0, 0);
        lcd.print("Connected!");
        delay(1000);

        uint8_t macAddr[6];
        WiFi.macAddress(macAddr);
        Serial.printf("Connected, mac address: %02x:%02x:%02x:%02x:%02x:%02x",
                      macAddr[0], macAddr[1], macAddr[2], macAddr[3], macAddr[4], macAddr[5]);
    }
    Serial.println("");
    Serial.print("Connected to ");
    Serial.println(SSID);
    Serial.print("IP address: ");
    Serial.println(WiFi.localIP());

    if (MDNS.begin("esp8266_mdns"))
    {
        Serial.println("MDNS responder started");
    }
}

// --- generate json payload ---
String generateJSONPayload()
{
    String json = "{";
    json += "\"device_id\": ";
    json += "\"";
    json += DEVICE_ID;
    json += "\"";
    json += ", ";
    json += "\"device_password\": ";
    json += "\"";
    json += DEVICE_PASSWORD;
    json += "\"";
    json += ", ";
    json += "\"temperature_c\": ";
    json += temperatureC != -1000.0 ? String(temperatureC, 2) : "null";
    json += ", ";
    json += "\"humidity\": ";
    json += humidity != -1000.0 ? String(humidity, 2) : "null";
    json += ", ";
    json += "\"rain\": ";
    json += String(rainMeasure, 2);
    json += ", ";
    json += "\"is_raining\": ";
    json += rainDigitalValue == 0 ? "true" : "false";
    json += ", ";
    json += "\"gps_lat\": ";
    json += lat_str != "" ? lat_str : "null";
    json += ", ";
    json += "\"gps_lng\": ";
    json += lng_str != "" ? lng_str : "null";
    json += "}";
    return json;
}

// --- On-Board Web Server Route Handlers ---
void indexRouteHandler()
{
    String jsonPayload = generateJSONPayload();
    Serial.println(jsonPayload);
    server.send(200, "application/json", jsonPayload);
}
void routeNotFound()
{
    String message = "404! Not Found";
    message += "URI";
    message += server.uri();
    message += "Method ";
    message += (server.method() == HTTP_GET) ? "GET" : "POST";
    message += "Arguments ";
    message += server.args();
    message += "";
    for (uint8_t i = 0; i < server.args(); i++)
    {
        message += " " + server.argName(i) + ": " + server.arg(i) + "";
    }
    server.send(404, "text/plain", message);
}
